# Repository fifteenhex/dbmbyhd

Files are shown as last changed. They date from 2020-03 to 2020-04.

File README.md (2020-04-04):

# dbmbyhd
Don't Blame Me if it Burns Your House Down - RT9525GQW LiPo charger breakout

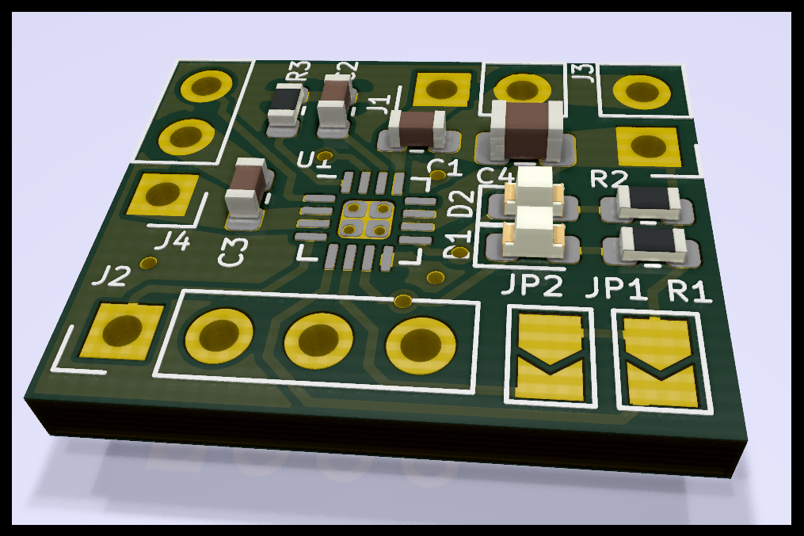
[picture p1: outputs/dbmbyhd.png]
omnomnom


## WHY?!

The RT9525GQW has active power path management that means the load is switched to your
input source instead of the load being powered from the battery while the charger
is trying to charge it. Woot!

## PCBs/Components

- PCB is shared on OSHPark; https://oshpark.com/shared_projects/hrCHnlJL
- The RT9525QGW is available from various suppliers on AliExpress for about $1, On taobao they are about $.50
- Get a cheap 0603 resistor/cap kit for the passives. Buy a stick of 10uF 0805 caps from ebay or whatever.

## Bugs

### Rev 0

- Missing via between gnd fill on the top and bottom layers. Means the iseta resistor and timer cap 
  aren't connected to ground

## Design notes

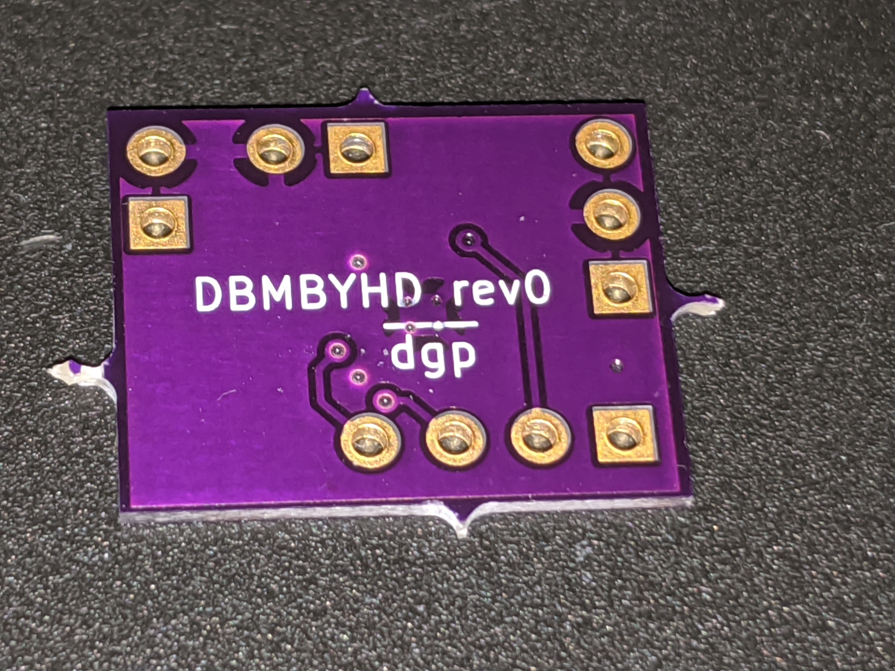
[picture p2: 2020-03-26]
photos/back.jpg

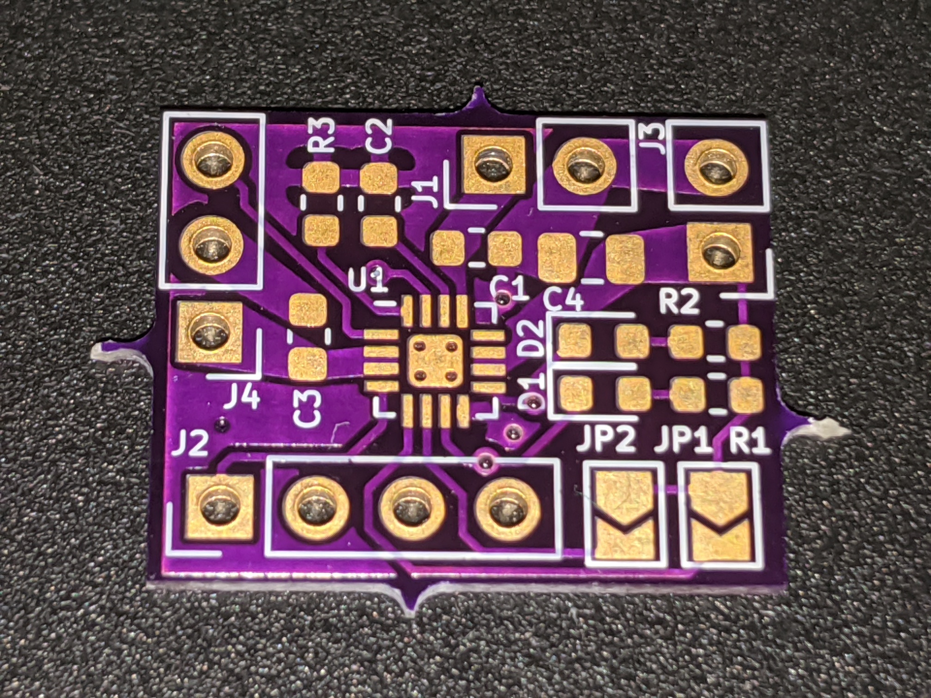
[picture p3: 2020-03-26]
photos/front.jpg

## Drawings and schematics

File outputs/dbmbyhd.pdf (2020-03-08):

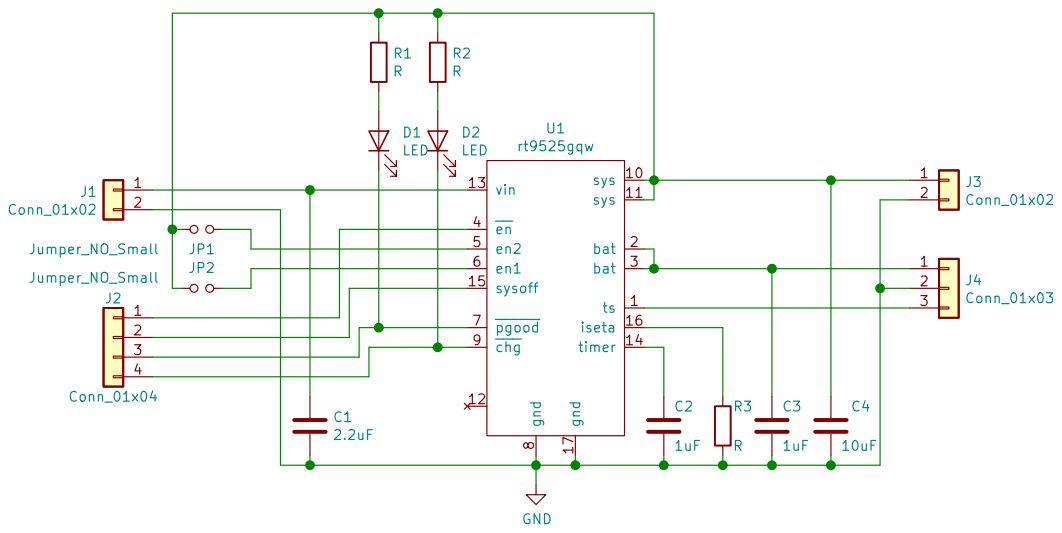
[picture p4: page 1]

en2 5
en1 6

File: dbmbyhd.sch Sheet: /
Id: 1/1 Title:

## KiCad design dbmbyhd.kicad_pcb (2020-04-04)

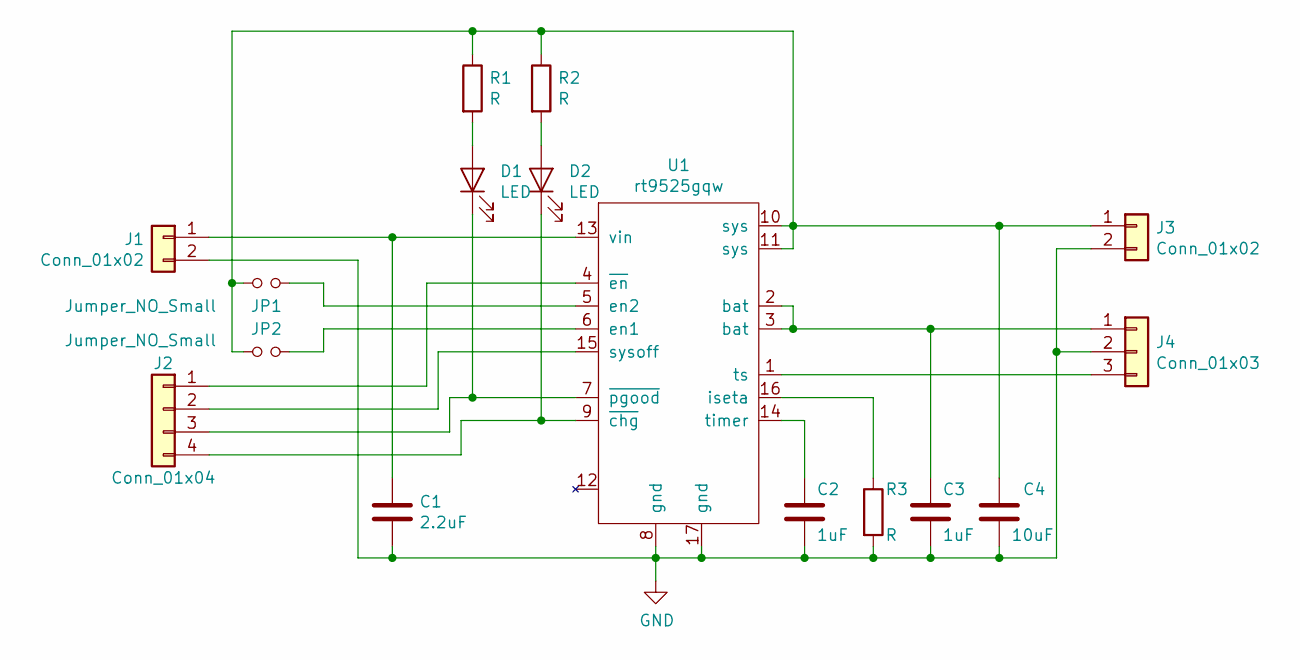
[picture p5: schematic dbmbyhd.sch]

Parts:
C1: 2.2uF; C_0603_1608Metric
C2, C3: 1uF; C_0603_1608Metric
C4: 10uF; C_0805_2012Metric
D1, D2: LED; LED_0603_1608Metric
J1, J3: Conn_01x02; PinHeader_1x02_P2.54mm_Vertical
J2: Conn_01x04; PinHeader_1x04_P2.54mm_Vertical
J4: Conn_01x03; PinHeader_1x03_P2.54mm_Vertical
JP1, JP2: Jumper_NO_Small; SolderJumper-2_P1.3mm_Open_TrianglePad1.0x1.5mm
R1, R2, R3: R; R_0603_1608Metric
U1: rt9525gqw; QFN-16-1EP_3x3mm_P0.5mm_EP1.45x1.45mm_ThermalVias

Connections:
GND: C1.2, C2.2, C3.2, C4.2, J1.2, J3.2, J4.2, R3.2, U1.8 (gnd), U1.17 (gnd)
unnamed: C1.1, J1.1, U1.13 (vin)
unnamed: C2.1, U1.14 (timer)
unnamed: C3.1, J4.1, U1.2 (bat), U1.3 (bat)
unnamed: C4.1, J3.1, JP1.1, JP2.1, R1.1, R2.1, U1.10 (sys), U1.11 (sys)
unnamed: D1.1 (K), J2.3, U1.7 (~pgood)
unnamed: D1.2 (A), R1.2
unnamed: D2.1 (K), J2.4, U1.9 (~chg)
unnamed: D2.2 (A), R2.2
unnamed: J2.1, U1.4 (~en)
unnamed: J2.2, U1.15 (sysoff)
unnamed: J4.3, U1.1 (ts)
unnamed: JP1.2, U1.5 (en2)
unnamed: JP2.2, U1.6 (en1)
unnamed: R3.1, U1.16 (iseta)

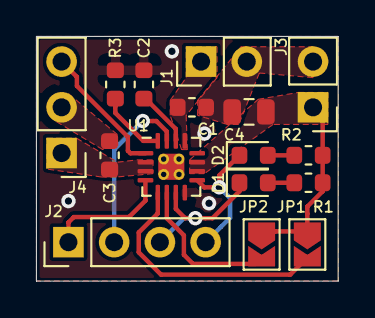
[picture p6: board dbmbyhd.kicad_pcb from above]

Board: 2 copper layers, 16.8 x 13.6 mm, 16 parts (0 on the bottom side), 15 nets.
